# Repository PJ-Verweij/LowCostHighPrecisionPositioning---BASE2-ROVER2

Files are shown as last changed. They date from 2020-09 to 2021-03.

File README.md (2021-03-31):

# LowCostHighPrecisionPositioning - BASE2, ROVER2

Here you can find all 3D models (SolidWorks 2019), PCB designs (KiCad) and documentation for the BASE2 and ROVER2 which have been designed during the master thesis project of Peter Verweij. <br/><br/>

The aim of this project was to create a low cost high precision positioning system for Ghana. <br/>
The showcase and explanation of the project can be found in this [showcase movie](https://www.youtube.com/watch?v=F1svl4LCIXA&feature=youtu.be&ab_channel=PeterVerweij)<br/><br/>

For the Ublox GNSS receiver configuration I refer to the work of hcwinsemius and kriete on the [RTK_GNSS github page](https://github.com/hcwinsemius/RTK_GNSS)<br/><br/>

Finally, the files and explanation to add a GPRS cellular connection to the raspberry PI can be found here aswell.<br/><br/>

It has to be noted that this project is in a prototype state. There is still a lot to be desired. For example: the custom PCBs connect prototype breakoutboards, there are no indicator lights in the devices, etcetera.

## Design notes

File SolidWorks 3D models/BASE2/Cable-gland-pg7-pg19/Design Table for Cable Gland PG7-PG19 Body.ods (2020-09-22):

Design Table for: Cable Gland PG7-PG19 Body
 | $DESCRIPTION | $COLOR | HexWidth@ProfileS | Height@Profile | CornerWidth@CornerFlatS | Dia@ConduitHoleS | Thickness@TopConduitWallS | Height@TopConduitWall | Thickness@BottomConduitWallS | Height@BottomConduitWall | Pitch@BottomNutProfileS | NumRev@ThreadSpiral | MajorDia@CableGlandNutToothProfileS | NumRev@CableGlandNutSpiral | Height@GlandLegProfile | InnerWidth@GlandLegProfileS | OuterWidth@GlandLegProfileS | SlantDist@GlandLegProfileS | NumInst@GLP CP | BottomChamferHeight@GasketHoldingProfileS | DiaControl@GasketHoldingProfileS | RoundProfileHeight@GasketHoldingProfileS | TopEdgeHeight@GasketHoldingProfileS | YDim@GasketHoldingProfileS
PG7 | PG7 | 8421504 | 16 | 4.4 | 1.4 | 8 | 1.35 | 9.2 | 1 | 8.7 | 1.27 | 5.5 | 12.5 | 3.5 | 5.6 | 1.5 | 0.6 | 0.2 | 14 | 0.4 | 0.25 | 1 | 1 | 2.8
PG9 | PG9 | 8421504 | 17.5 | 5 | 1.4 | 11.6 | 1 | 9.7 | 1 | 11 | 1.411 | 6.5 | 15.2 | 3.5 | 6.3 | 1.7 | 1 | 0.2 | 14 | 2.5 | 0.8 | 1.5 | 1.5 | 5.2
PG11 | PG11 | 8421504 | 21.5 | 5 | 1.6 | 14.5 | 1 | 10.5 | 1 | 9 | 1.411 | 4.5 | 18.6 | 4.5 | 8 | 1.6 | 1.4 | 0.2 | 18 | 2 | 1.25 | 1.5 | 2.5 | 4.5
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

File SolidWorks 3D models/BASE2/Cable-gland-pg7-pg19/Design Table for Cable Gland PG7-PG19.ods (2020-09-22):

Design Table for: Cable Gland PG7-PG19
 | $DESCRIPTION | $CONFIGURATION@Cable Gland PG7-PG19 Body<1> | $CONFIGURATION@Cable Gland PG7-PG19 Lock Nut<1> | $CONFIGURATION@Cable Gland PG7-PG19 Sleeve<1> | $CONFIGURATION@Cable Gland PG7-PG19 Washer<1> | $CONFIGURATION@Cable Gland PG7-PG19 Gland Nut<1>
PG7 | PG7 | PG7 | PG7 | PG7 | PG7 | PG7
PG9 | PG9 | PG9 | PG9 | PG9 | PG9 | PG9
PG11 | PG11 | PG11 | PG11 | PG11 | PG11 | PG11
PG13.5 | PG13.5 | PG13.5 | PG13.5 | PG13.5 | PG13.5 | PG13.5
PG16 | PG16 | PG16 | PG16 | PG16 | PG16 | PG16
PG19 | PG19 | PG19 | PG19 | PG19 | PG19 | PG19

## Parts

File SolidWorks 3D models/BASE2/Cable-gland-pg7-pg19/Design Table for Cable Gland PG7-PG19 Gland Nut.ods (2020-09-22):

Design Table for: Cable Gland PG7-PG19 Gland Nut
 | $DESCRIPTION | $COLOR | HexWidth@ProfileS | Height@Profile | CornerWidth@CornerFlatS | Dia@ConduitHoleS | NumRev@CableGlandNutSpiral | Dia@EjectionPinHoleS | DiaControl@RoundTopProfileS | FilleBodyHeight@RoundTopProfileS | FilletStartHeight@RoundTopProfileS | Height@RoundTopProfileS | TopRadius@RoundTopProfileS
PG7 | PG7 | 8421504 | 15.7 | 9.5 | 2.5 | 13 | 3.5 | 1 | 3.8 | 4.5 | 1.5 | 1.6 | 4
PG9 | PG9 | 8421504 | 18.5 | 9.5 | 1 | 16 | 3.5 | 1.2 | 4.8 | 6 | 3 | 1.4 | 5
PG11 | PG11 | 8421504 | 22 | 11.5 | 3 | 19 | 4.5 | 1.3 | 5.5 | 5.5 | 3 | 2.4 | 7
PG13.5 | PG13.5 | 8421504 | 23.5 | 13 | 2.5 | 21 | 5.5 | 1.4 | 6.3 | 6.5 | 3 | 2.6 | 6
PG16 | PG16 | 8421504 | 26.5 | 12.5 | 5 | 22.5 | 5.5 | 1.4 | 6.9 | 6.5 | 3.5 | 2 | 8
PG19 | PG19 | 8421504 | 27.5 | 14.5 | 4 | 24.5 | 5.5 | 1.4 | 7.8 | 5.5 | 2 | 2 | 6

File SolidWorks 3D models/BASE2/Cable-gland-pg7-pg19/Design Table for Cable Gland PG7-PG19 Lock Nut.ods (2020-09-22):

Design Table for: Cable Gland PG7-PG19 Lock Nut
 | $DESCRIPTION | $COLOR | HexWidth@ProfileS | Height@Profile | CornerWidth@CornerFlatS | MajorDia@ThreadOuterDiaRef | Pitch@LockNutThreadProfile
PG7 | PG7 | 8421504 | 17.8 | 4.4 | 1.8 | 12.5 | 1.27
PG9 | PG9 | 8421504 | 22 | 5 | 2 | 15.2 | 1.411
PG11 | PG11 | 8421504 | 23.6 | 5 | 2.4 | 18.6 | 1.411
PG13.5 | PG13.5 | 8421504 | 26.4 | 5 | 2.8 | 20.4 | 1.411
PG16 | PG16 | 8421504 | 28.6 | 6 | 2.4 | 22.5 | 1.411
PG19 | PG19 | 8421504 | 29.6 | 6 | 3 | 24 | 1.411

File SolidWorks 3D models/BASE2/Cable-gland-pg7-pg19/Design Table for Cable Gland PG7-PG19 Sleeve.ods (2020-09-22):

Design Table for: Cable Gland PG7-PG19 Sleeve
 | $DESCRIPTION | $COLOR | OD@ProfileS | IDControl@ProfileS | Height@Profile
PG7 | PG7 | 8421504 | 8.4 | 1 | 6.7
PG9 | PG9 | 8421504 | 10.9 | 1.4 | 7.8
PG11 | PG11 | 8421504 | 13.7 | 1.6 | 8
PG13.5 | PG13.5 | 8421504 | 15.7 | 1.6 | 8
PG16 | PG16 | 8421504 | 17.4 | 1.7 | 8
PG19 | PG19 | 8421504 | 18.4 | 1.7 | 9

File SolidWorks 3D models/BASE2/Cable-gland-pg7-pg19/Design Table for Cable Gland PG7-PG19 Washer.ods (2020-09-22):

Design Table for: Cable Gland PG7-PG19 Washer
 | $DESCRIPTION | $COLOR | OD@ProfileS | IDControl@ProfileS | Height@Profile
PG7 | PG7 | 8421504 | 16.6 | 2.2 | 1.2
PG9 | PG9 | 8421504 | 19.7 | 2.5 | 1.2
PG11 | PG11 | 8421504 | 23 | 2.8 | 1.2
PG13.5 | PG13.5 | 8421504 | 25 | 3 | 1.2
PG16 | PG16 | 8421504 | 27.6 | 3 | 1.2
PG19 | PG19 | 8421504 | 29.6 | 3 | 1.2

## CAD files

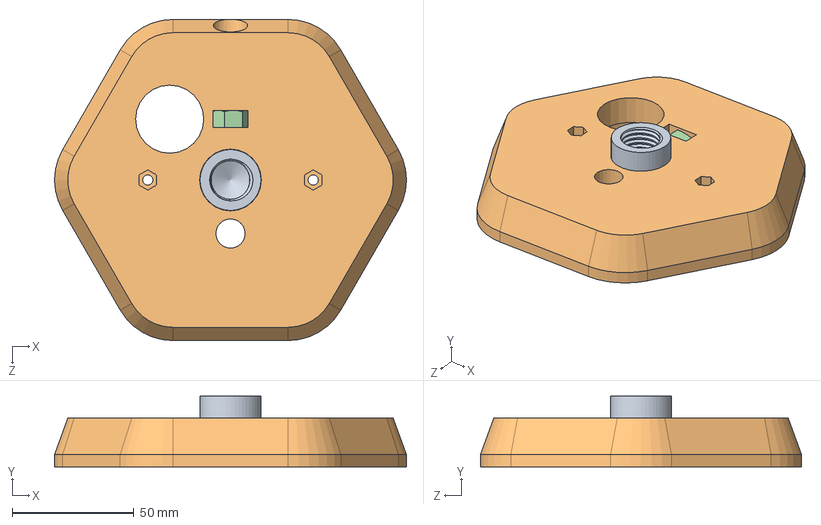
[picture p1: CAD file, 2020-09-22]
SolidWorks 3D models/BASE2/Antennatop/antennatop58-11uncadapter.SLDASM
144.7 x 29.0 x 132.0 mm
thread adapter antenna top
antenna top
socket head cap screw_am
hex nut style 2_am

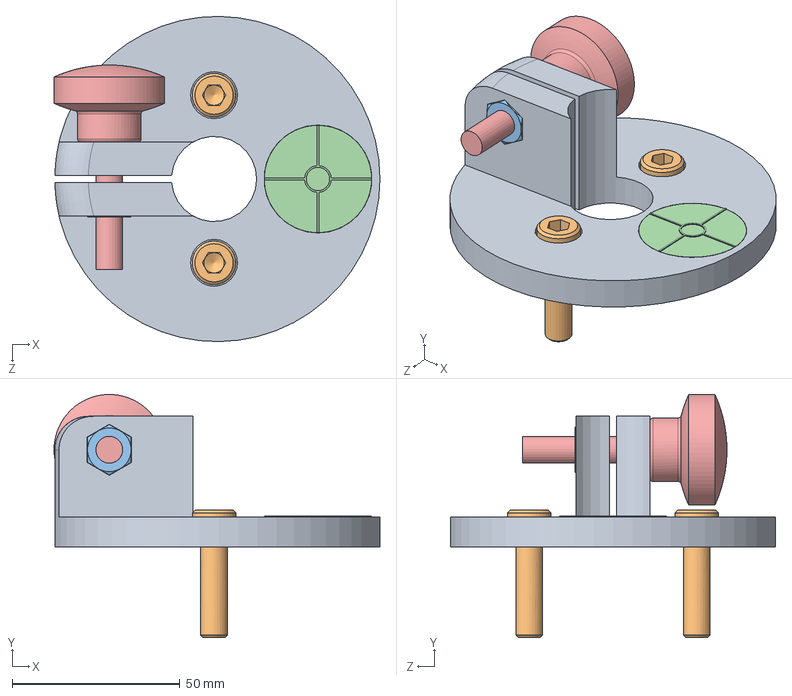
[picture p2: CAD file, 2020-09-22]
SolidWorks 3D models/BASE2/Tripodclamp/Base.Tripodclamp.SLDASM
97.2 x 72.5 x 97.0 mm
Universal.M.poleclamp
socket head cap screw_am x 2
hex nut style 1_am
Universal.B.level_32mm
Universal.B.knob_m8

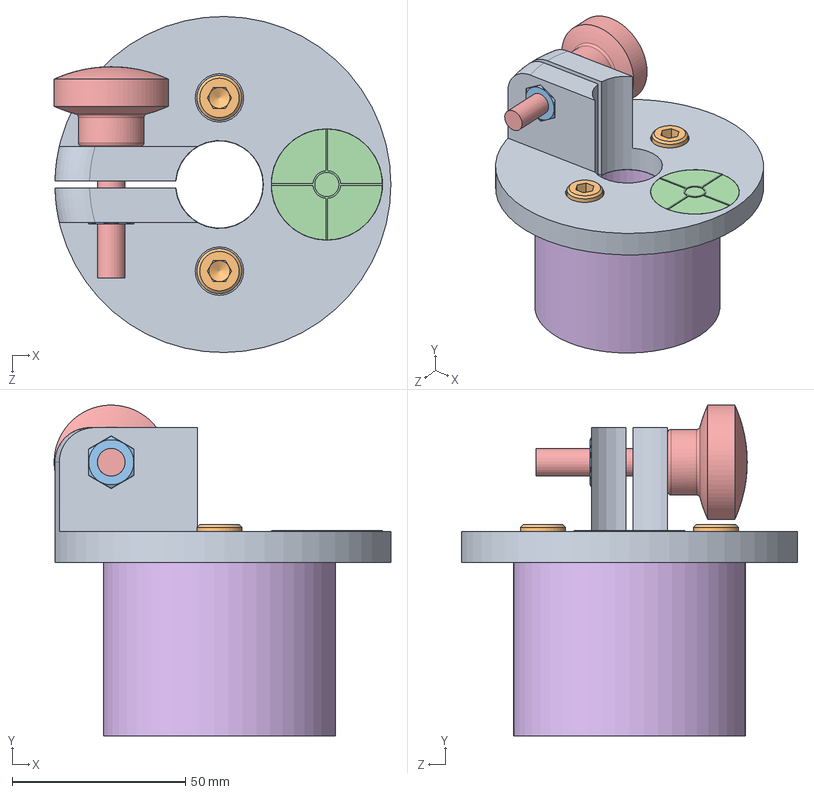
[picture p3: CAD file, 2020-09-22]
SolidWorks 3D models/ROVER2/Tripodclamp/Rover.Tripodclamp.SLDASM
97.2 x 95.5 x 97.0 mm
Universal.M.poleclamp
socket head cap screw_am x 2
hex nut style 1_am x 3
Universal.B.level_32mm
Universal.B.knob_m8
Rover.M.open_tripod_coupler

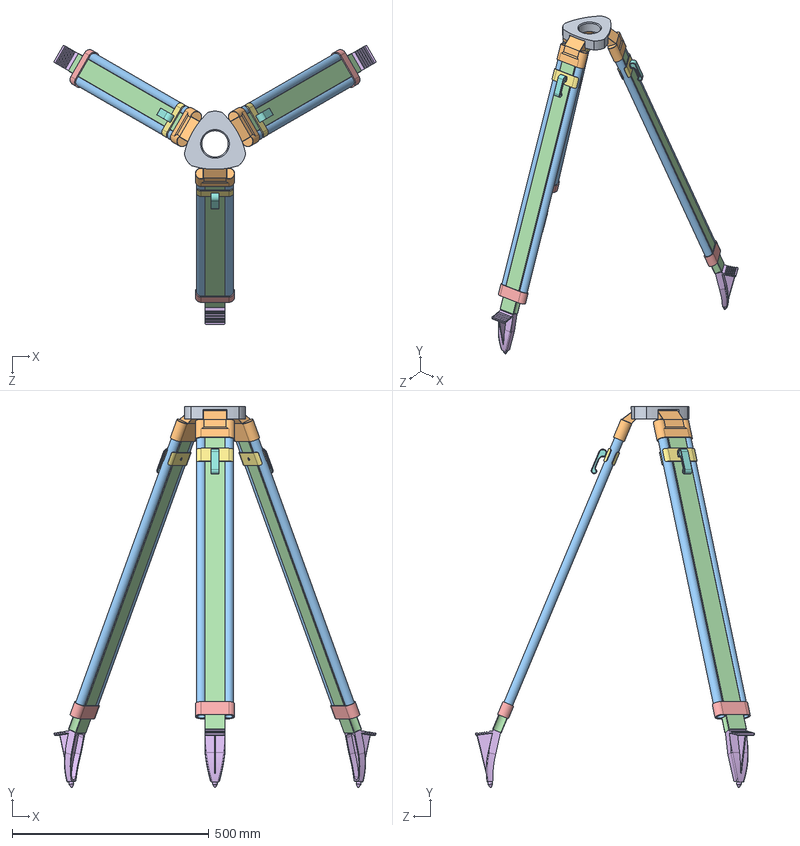
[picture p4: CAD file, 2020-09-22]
SolidWorks 3D models/shared parts ROVER2 and BASE2/Tripod/Universal.Tripod.Assembly.SLDASM
817.6 x 967.8 x 708.9 mm
Tripod.baseplate
Tripodleg.hinge x 3
Tripodleg.tube x 6
Tripodleg.profile x 3
Tripodleg.lower_guide x 3
Tripodleg.feet x 3
Tripodleg.clamp x 6
Tripodleg.clampclip x 3

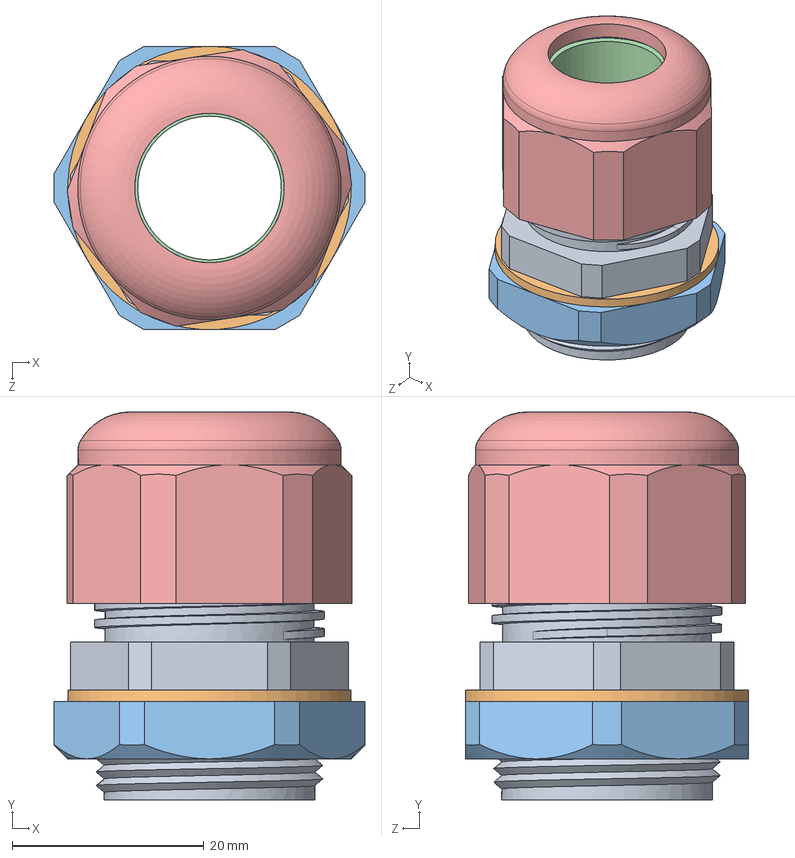
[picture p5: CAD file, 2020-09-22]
SolidWorks 3D models/BASE2/Cable-gland-pg7-pg19/Cable Gland PG7-PG19.SLDASM
32.4 x 40.5 x 29.6 mm
Cable Gland PG7-PG19 Body
Cable Gland PG7-PG19 Washer
Cable Gland PG7-PG19 Lock Nut
Cable Gland PG7-PG19 Sleeve
Cable Gland PG7-PG19 Gland Nut

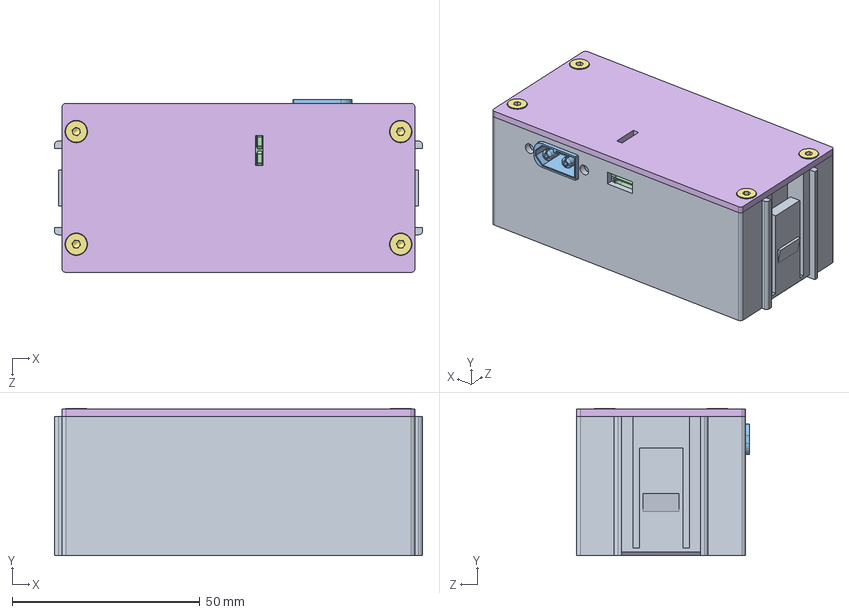
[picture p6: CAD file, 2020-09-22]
SolidWorks 3D models/ROVER2/Rover.Battery.Assembly.SLDASM
98.0 x 39.2 x 46.0 mm
Rover.M.Batteryhousing
Rover.B.18650x2_holder
Universal.B.XT60E-M
Universal.B.TP4056
Rover.M.BatteryPCB
Rover.M.BatteryLid
socket countersunk head screw_din x 4

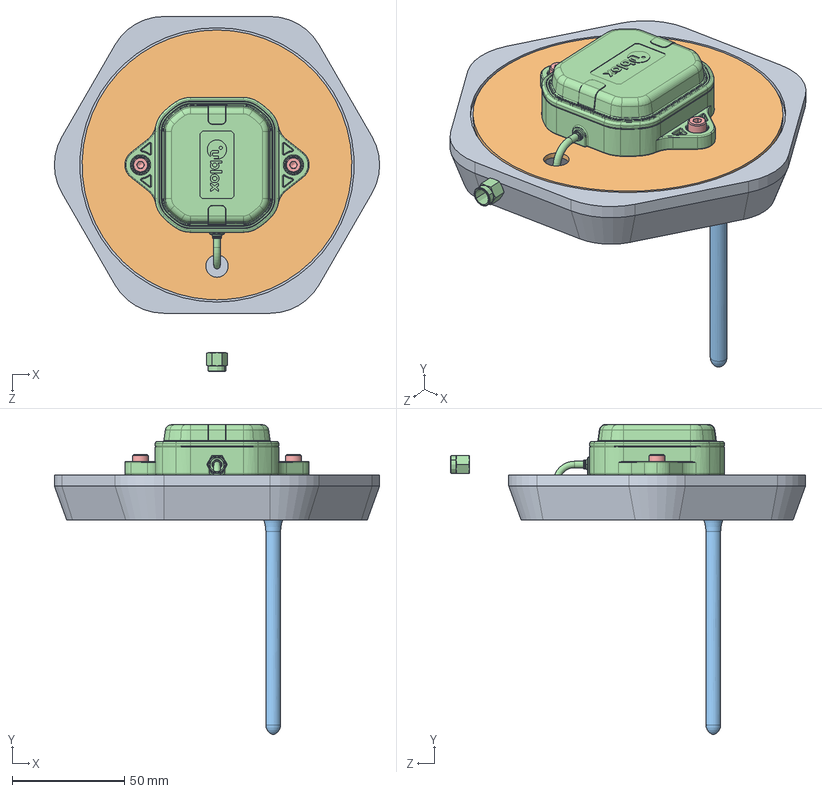
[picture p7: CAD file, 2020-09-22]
SolidWorks 3D models/BASE2/Antennatop/Base.Antennatop.Assembly.SLDASM
144.7 x 138.1 x 157.9 mm
Base.M.Antennatop
Universal.M.groundplate
Base.B.cellular_antenna
Universal.B.GNSS_antenna_ANN-MB-00(SMA)
socket head cap screw_am x 3
hex nut style 1_am x 2

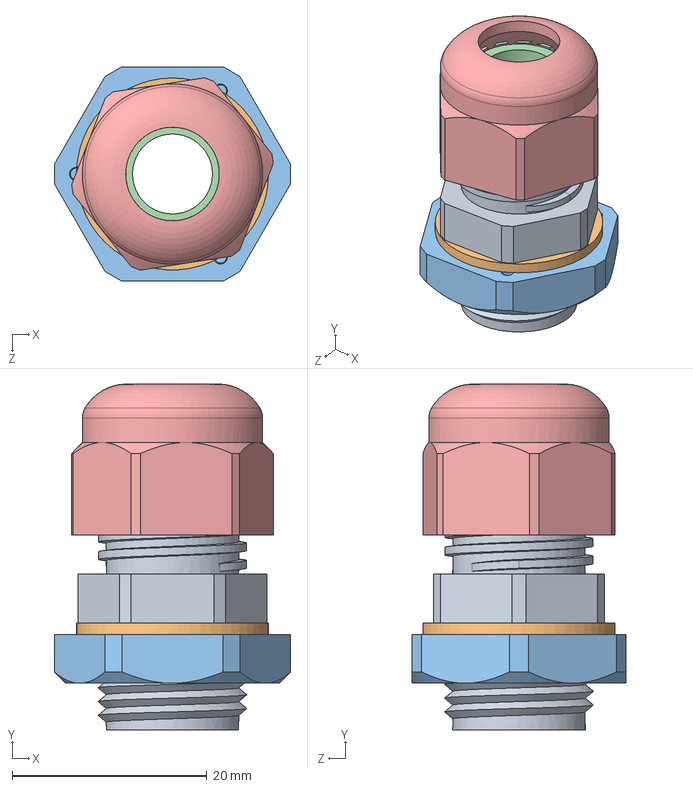
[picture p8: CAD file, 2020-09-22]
SolidWorks 3D models/BASE2/Cable-gland-pg7-pg19/Base.B.PG9.SLDASM
24.2 x 35.5 x 22.0 mm
Cable Gland PG7-PG19 Body
Cable Gland PG7-PG19 Washer
Cable Gland PG7-PG19 Sleeve
Cable Gland PG7-PG19 Gland Nut

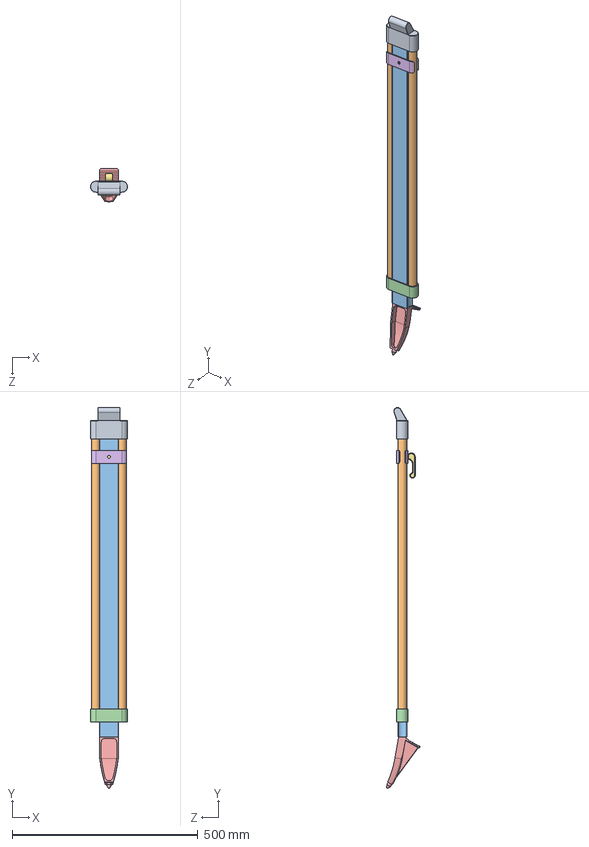
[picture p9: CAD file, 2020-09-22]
SolidWorks 3D models/shared parts ROVER2 and BASE2/Tripod/Tripod.leg.SLDASM
100.0 x 1026.9 x 90.4 mm
Tripodleg.hinge
Tripodleg.tube x 2
Tripodleg.profile
Tripodleg.lower_guide
Tripodleg.feet
Tripodleg.clamp x 2
Tripodleg.clampclip

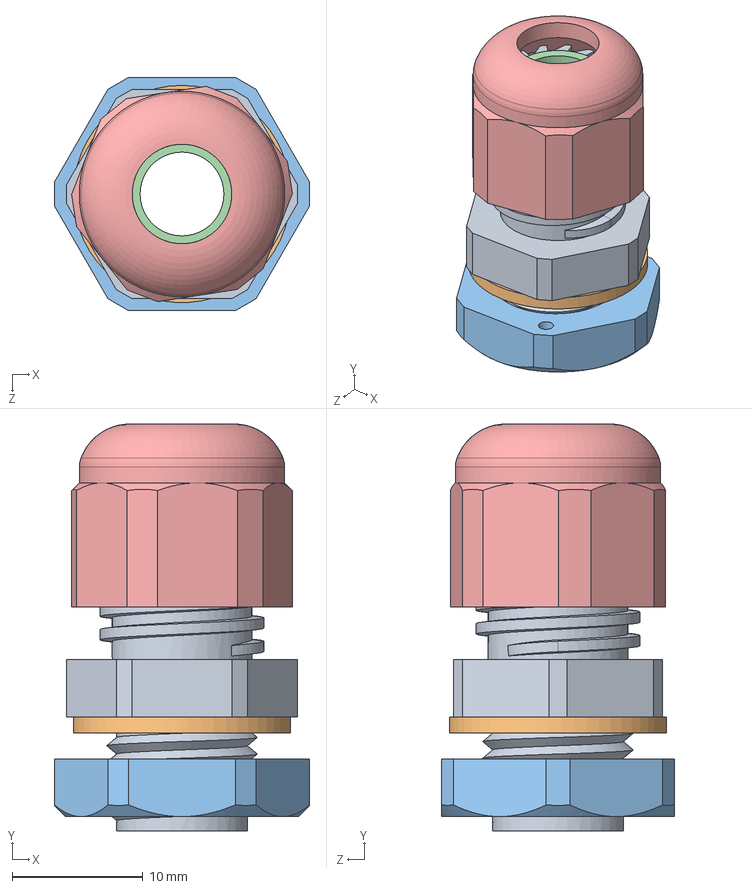
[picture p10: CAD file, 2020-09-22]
SolidWorks 3D models/ROVER2/Cable-gland-pg7-pg19/Rover.B.PG7.SLDASM
19.5 x 31.1 x 17.8 mm
Cable Gland PG7-PG19 Body
Cable Gland PG7-PG19 Washer
Cable Gland PG7-PG19 Lock Nut
Cable Gland PG7-PG19 Sleeve
Cable Gland PG7-PG19 Gland Nut

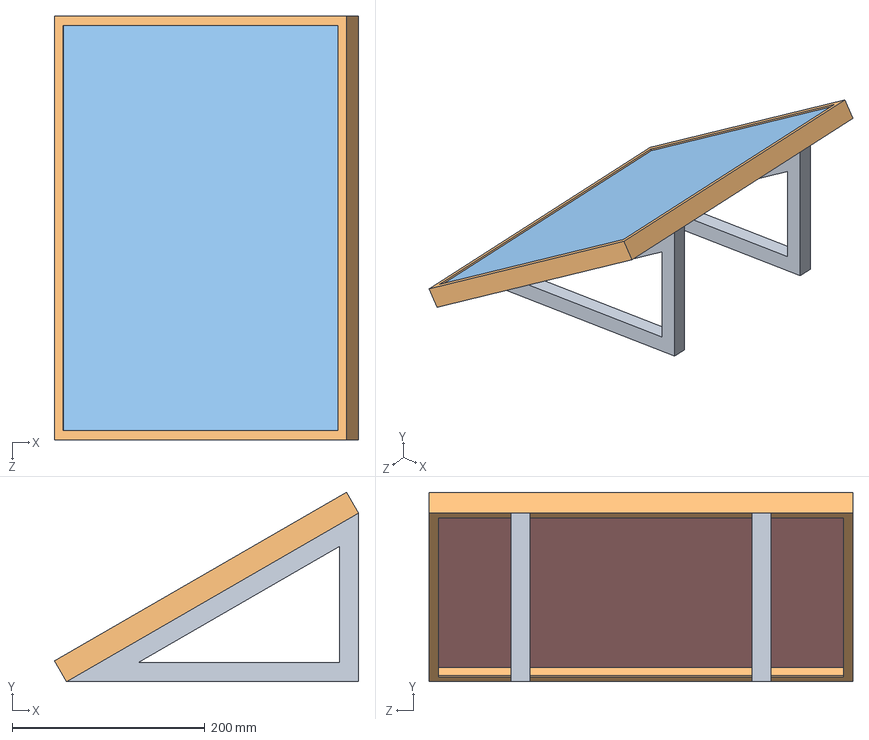
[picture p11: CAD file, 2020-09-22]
SolidWorks 3D models/BASE2/Solarpanel/Base.Solarpanel.Assembly.SLDASM
315.6 x 196.7 x 440.0 mm
Base.M.example_solarpanel_stand x 2
Solarpanel.sides
Solarpanel.glass
Solarpanel.cells
Solarpanel.backplate

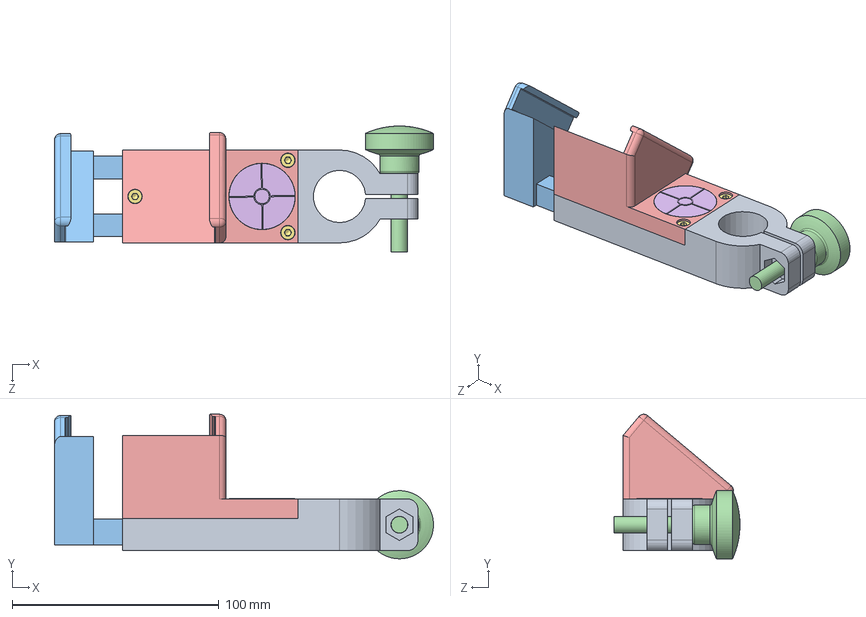
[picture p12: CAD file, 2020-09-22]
SolidWorks 3D models/ROVER2/Phoneholder/Rover.Phoneholder.Assembly.SLDASM
183.5 x 70.0 x 61.0 mm
Rover.M.Phoneholder_base
Rover.B.spring
Rover.M.Phoneholder_movablepart
Universal.B.knob_m8
Rover.M.Phoneholder_toppart
Universal.B.level_32mm
socket head cap screw_iso x 3

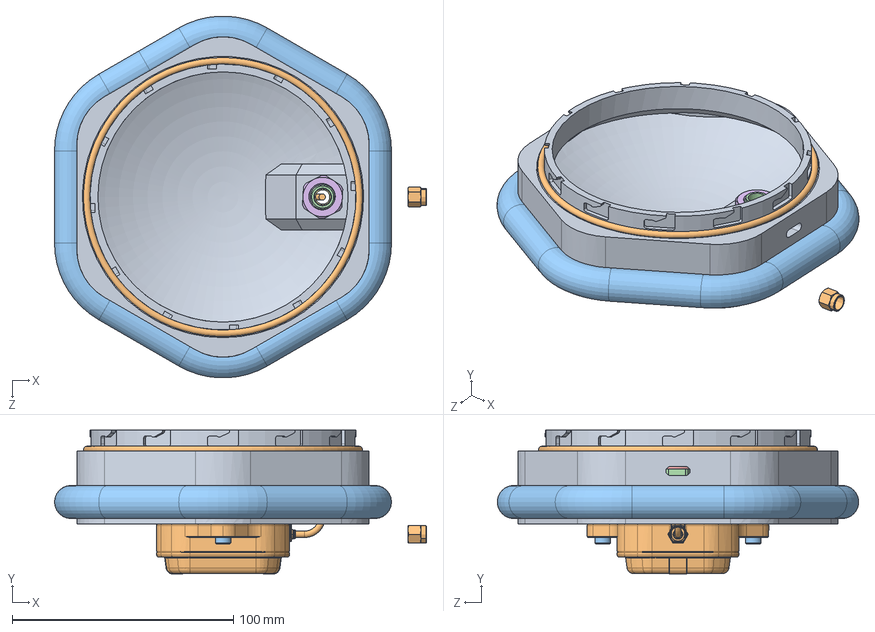
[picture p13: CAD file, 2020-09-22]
SolidWorks 3D models/ROVER2/Rover.Cap.Assembly.SLDASM
168.0 x 65.0 x 163.2 mm
Rover.M.cap
Rover.B.3x118_o-ring
Rover.M.Cap_rubber
Cable Gland PG7-PG19 Body
Cable Gland PG7-PG19 Washer
Cable Gland PG7-PG19 Lock Nut
Cable Gland PG7-PG19 Sleeve
Cable Gland PG7-PG19 Gland Nut
Universal.M.groundplate
Universal.B.GNSS_antenna_ANN-MB-00(SMA)
socket head cap screw_am x 2
hex nut style 3_am x 2

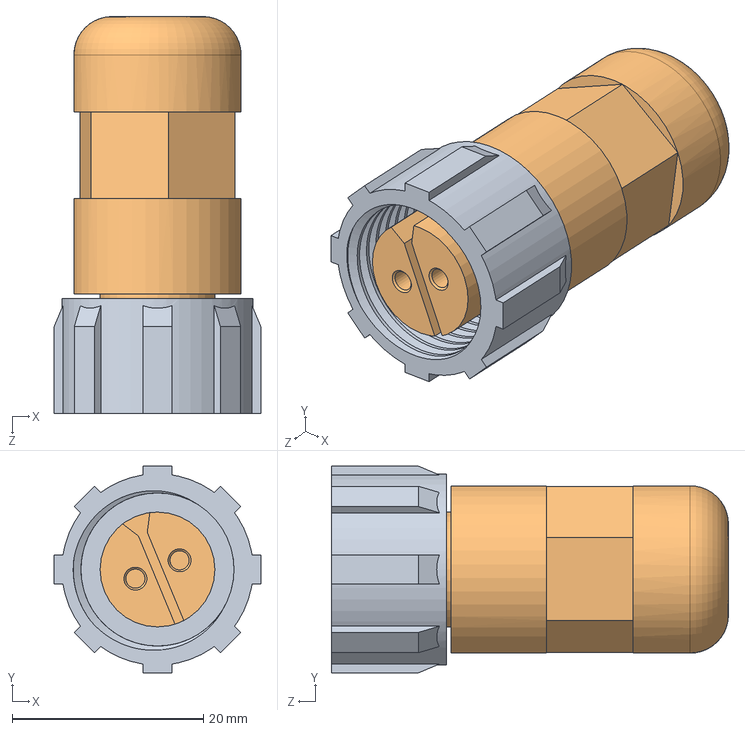
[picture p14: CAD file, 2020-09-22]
SolidWorks 3D models/BASE2/Base.Solarconnector.Assembly.SLDASM
21.6 x 21.6 x 41.5 mm
Base.B.solarconnector_turnablecap
Base.B.solarconnector_cablegland

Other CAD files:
SolidWorks 3D models/BASE2/Solarpanel/Base.B.solarpanel_victron_20watt.SLDASM
SolidWorks 3D models/BASE2/Base.Leg.Assembly.SLDASM
SolidWorks 3D models/BASE2/Base.Cap.Assembly.SLDASM
SolidWorks 3D models/BASE2/Antennatop/Base.B.cellular_antenna.SLDPRT
SolidWorks 3D models/BASE2/Antennatop/Base.M.Antennatop.SLDPRT
SolidWorks 3D models/BASE2/Antennatop/thread adapter antenna top.SLDPRT
SolidWorks 3D models/BASE2/Antennatop/thread adapter.SLDDRW
SolidWorks 3D models/BASE2/Base.B.18650x4_holder.SLDPRT
SolidWorks 3D models/BASE2/Base.B.3x106_o-ring.SLDPRT
SolidWorks 3D models/BASE2/Base.B.M16_powerconnector_Applamp.SLDPRT
SolidWorks 3D models/BASE2/Base.B.Rubber_Feet.SLDPRT
SolidWorks 3D models/BASE2/Base.B.SMA_bulkhead.SLDPRT
SolidWorks 3D models/BASE2/Base.B.Square_Tube_Cap.SLDPRT
SolidWorks 3D models/BASE2/Base.B.cn3772_MPPT_regulator.SLDPRT
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

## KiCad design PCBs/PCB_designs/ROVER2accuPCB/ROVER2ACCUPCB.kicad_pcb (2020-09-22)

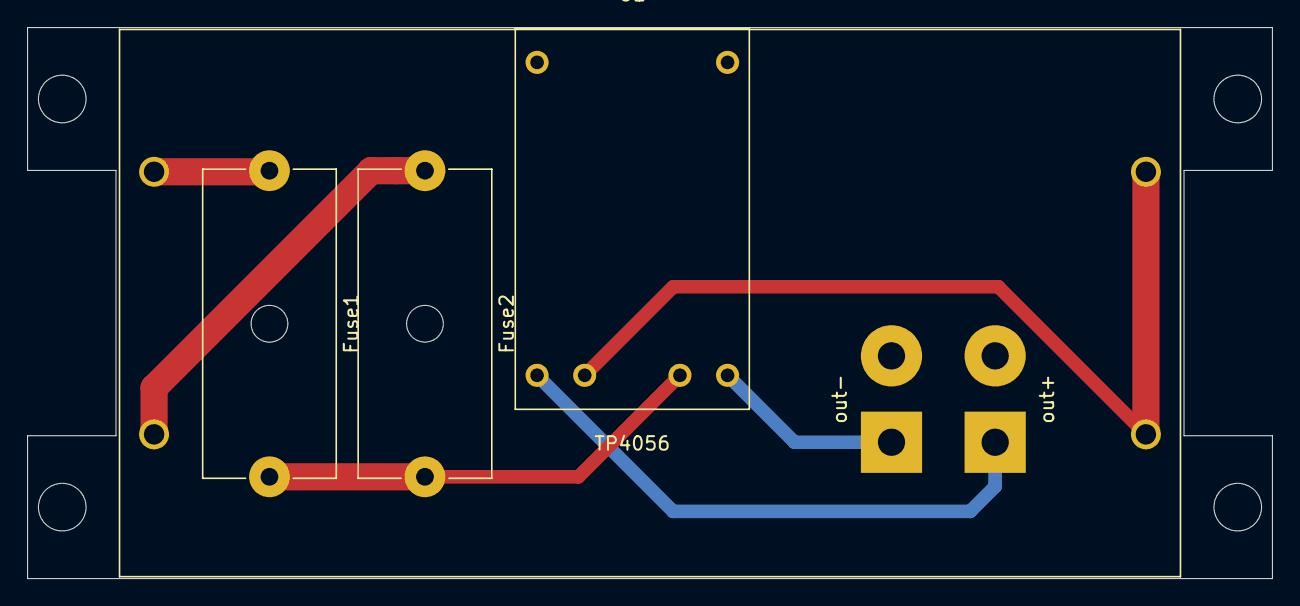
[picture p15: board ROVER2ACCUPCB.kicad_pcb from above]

Board: 2 copper layers, 91.5 x 40.5 mm, 6 parts (0 on the bottom side), 6 nets.

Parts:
B1: Batteryholder2x18650
F1: Fuse1; Fuseholder_Cylinder-5x20mm_Schurter_0031_8201_Horizontal_Op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
F2: Fuse2; Fuseholder_Cylinder-5x20mm_Schurter_0031_8201_Horizontal_Op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
J1: out-; SolderWirePad_1x02_P7.62mm_Drill2mm
J2: out+; SolderWirePad_1x02_P7.62mm_Drill2mm
U1: TP4056

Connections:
unnamed: B1.1, F1.2
unnamed: B1.2, B1.4, U1.3
unnamed: B1.3, F2.2
unnamed: F1.1, F2.1, U1.2
unnamed: J1.1, U1.1
unnamed: J2.1, U1.4

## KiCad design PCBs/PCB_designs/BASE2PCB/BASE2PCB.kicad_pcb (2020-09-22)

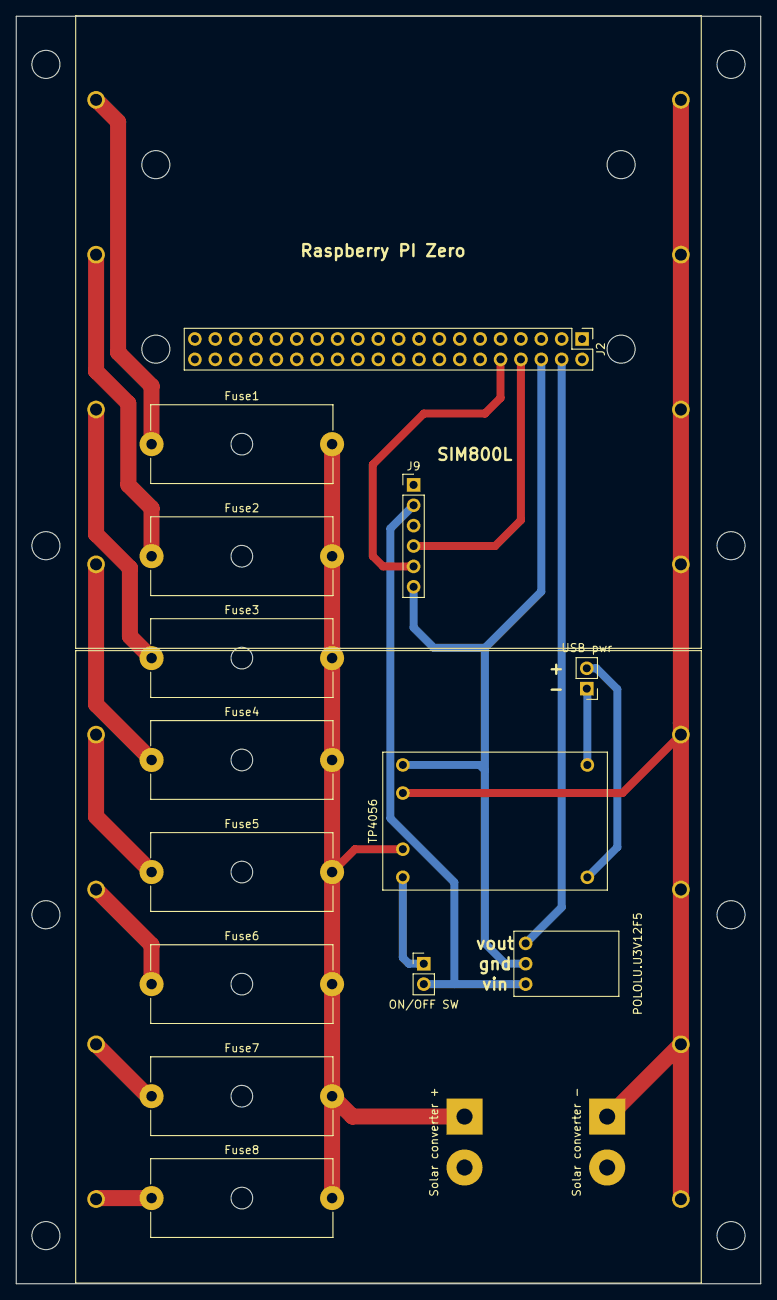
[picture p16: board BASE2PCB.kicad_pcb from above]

Board: 2 copper layers, 92.8 x 158.0 mm, 18 parts (0 on the bottom side), 18 nets.

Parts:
F1: Fuse5; Fuseholder_Cylinder-5x20mm_Schurter_0031_8201_Horizontal_Op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
F2: Fuse6; Fuseholder_Cylinder-5x20mm_Schurter_0031_8201_Horizontal_Op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
F3: Fuse7; Fuseholder_Cylinder-5x20mm_Schurter_0031_8201_Horizontal_Op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
F4: Fuse8; Fuseholder_Cylinder-5x20mm_Schurter_0031_8201_Horizontal_Op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
F5: Fuse1; Fuseholder_Cylinder-5x20mm_Schurter_0031_8201_Horizontal_Op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
F6: Fuse2; Fuseholder_Cylinder-5x20mm_Schurter_0031_8201_Horizontal_Op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
F7: Fuse3; Fuseholder_Cylinder-5x20mm_Schurter_0031_8201_Horizontal_Op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
F8: Fuse4; Fuseholder_Cylinder-5x20mm_Schurter_0031_8201_Horizontal_Op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
J1: ON/OFF SW; PinHeader_1x02_P2.54mm_Vertical
J2: Conn_02x20_Odd_Even; PinHeader_2x20_P2.54mm_Vertical
J3: USB pwr; PinHeader_1x02_P2.54mm_Vertical
J4: Solar converter +; SolderWirePad_1x02_P7.62mm_Drill2mm
J6: Solar converter -; SolderWirePad_1x02_P7.62mm_Drill2mm
J9: Conn_01x06_Male; PinHeader_1x06_P2.54mm_Vertical
U1: POLOLU.U3V12F5; Pololu.U3V12F5
U2, U3: Batteryholder; Batteryholder4x18650
U4: TP4056

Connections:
unnamed: F1.1, F2.1, F3.1, F4.1, F5.1, F6.1, F7.1, F8.1, J4.1, U4.2
unnamed: F1.2, U2.1
unnamed: F2.2, U2.3
unnamed: F3.2, U2.5
unnamed: F4.2, U2.7
unnamed: F5.2, U3.1
unnamed: F6.2, U3.3
unnamed: F7.2, U3.5
unnamed: F8.2, U3.7
unnamed: J1.1, U4.1
unnamed: J1.2, J9.2, U1.1
unnamed: J2.4, U1.3
unnamed: J2.6, J9.6, U1.2, U4.4
unnamed: J2.8, J9.4
unnamed: J2.10, J9.5
unnamed: J3.1, U4.5
unnamed: J3.2, U4.6
unnamed: J6.1, U2.2, U2.4, U2.6, U2.8, U3.2, U3.4, U3.6, U3.8, U4.3

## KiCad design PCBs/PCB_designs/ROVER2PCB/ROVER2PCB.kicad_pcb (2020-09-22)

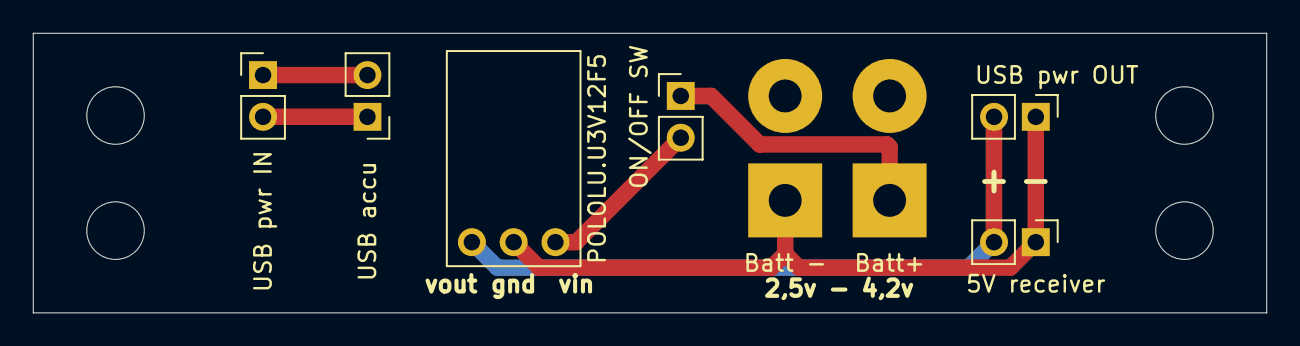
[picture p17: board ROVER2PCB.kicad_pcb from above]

Board: 2 copper layers, 75.0 x 17.0 mm, 8 parts (0 on the bottom side), 6 nets.

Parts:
J1: Batt+; SolderWirePad_1x02_P7.62mm_Drill2mm
J2: Batt -; SolderWirePad_1x02_P7.62mm_Drill2mm
J3: USB accu; PinHeader_1x02_P2.54mm_Vertical
J4: USB pwr IN; PinHeader_1x02_P2.54mm_Vertical
J5: USB pwr OUT; PinHeader_1x02_P2.54mm_Vertical
J6: 5V receiver; PinHeader_1x02_P2.54mm_Vertical
J7: ON/OFF SW; PinHeader_1x02_P2.54mm_Vertical
U1: POLOLU.U3V12F5; Pololu.U3V12F5

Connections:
unnamed: J1.1, J7.1
unnamed: J2.1, J5.1, J6.1, U1.2
unnamed: J3.1, J4.2
unnamed: J3.2, J4.1
unnamed: J5.2, J6.2, U1.3
unnamed: J7.2, U1.1
